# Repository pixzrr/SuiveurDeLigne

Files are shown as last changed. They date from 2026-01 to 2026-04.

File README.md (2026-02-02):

# SuiveurDeLigne

## Etape 1 : Créer le PCB
PCB : 100%


Carte imprimée

## Etape 2 : Soudure
Soudure : 100%

Tests : 8/9 validés (89%)

## Etape 3 : Programmation

Création des fonctions tests : terminé

Programmation en logique binaire (principe de sur-correction constante) : terminée

Programmation en logique analogique (s'adapter parfaitement à la courbe en fonction des nuances de gris) : en cours

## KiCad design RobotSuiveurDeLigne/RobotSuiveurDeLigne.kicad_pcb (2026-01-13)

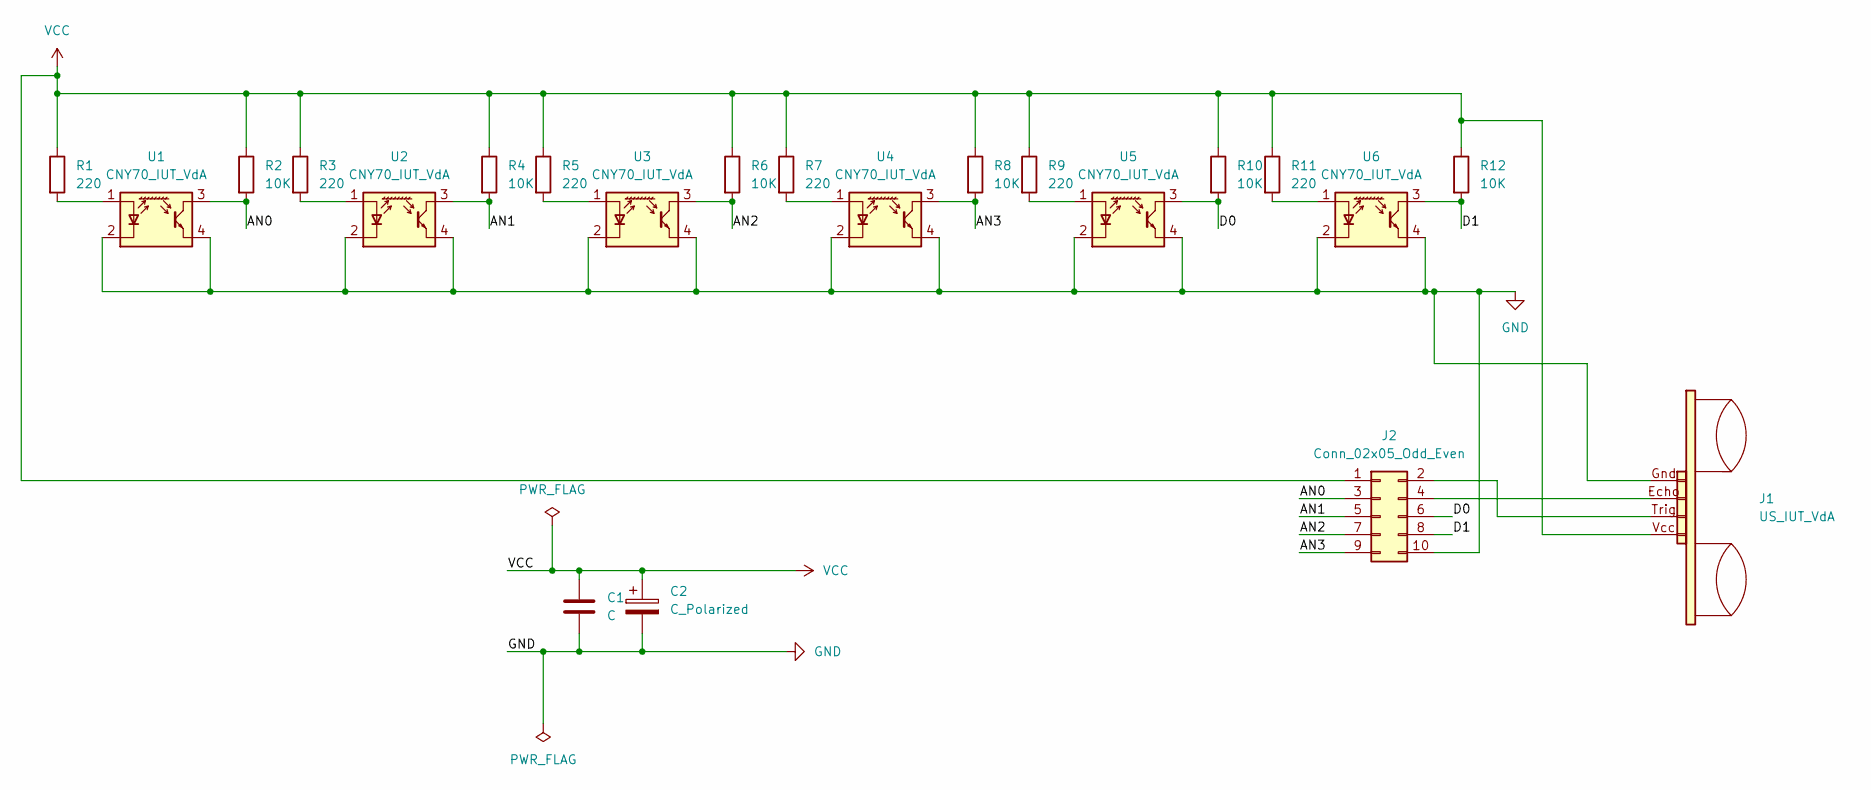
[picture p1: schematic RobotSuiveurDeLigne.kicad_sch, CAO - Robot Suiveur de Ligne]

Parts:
C1: C; C_Rect_L7.0mm_W6.5mm_P5.00mm
C2: C_Polarized; CP_Radial_D6.3mm_P2.50mm
J1: US_IUT_VdA; UltraSon_IUT_VdA
J2: Conn_02x05_Odd_Even; IDC-Header_2x05_P2.54mm_Horizontal
R1, R3, R5, R7, R9, R11: 220; R_Axial_DIN0207_L6.3mm_D2.5mm_P10.16mm_Horizontal
R2, R4, R6, R8, R10, R12: 10K; R_Axial_DIN0207_L6.3mm_D2.5mm_P10.16mm_Horizontal
U1, U2, U3, U4, U5, U6: CNY70_IUT_VdA; Vishay_CNY70

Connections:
/AN0: J2.3, R2.2, U1.3 (C)
/AN1: J2.5, R4.2, U2.3 (C)
/AN2: J2.7, R6.2, U3.3 (C)
/AN3: J2.9, R8.2, U4.3 (C)
/D0: J2.6, R10.2, U5.3 (C)
/D1: J2.8, R12.2, U6.3 (C)
GND: C1.2, C2.2, J1.Gnd, J2.10, U1.2 (K), U1.4 (E), U2.2 (K), U2.4 (E), U3.2 (K), U3.4 (E), U4.2 (K), U4.4 (E), U5.2 (K), U5.4 (E), U6.2 (K), U6.4 (E)
unnamed: J1.Trig, J2.2
unnamed: J1.Echo, J2.4
unnamed: R1.2, U1.1 (A)
unnamed: R3.2, U2.1 (A)
unnamed: R5.2, U3.1 (A)
unnamed: R7.2, U4.1 (A)
unnamed: R9.2, U5.1 (A)
unnamed: R11.2, U6.1 (A)
VCC: C1.1, C2.1, J1.Vcc, J2.1, R1.1, R2.1, R3.1, R4.1, R5.1, R6.1, R7.1, R8.1, R9.1, R10.1, R11.1, R12.1

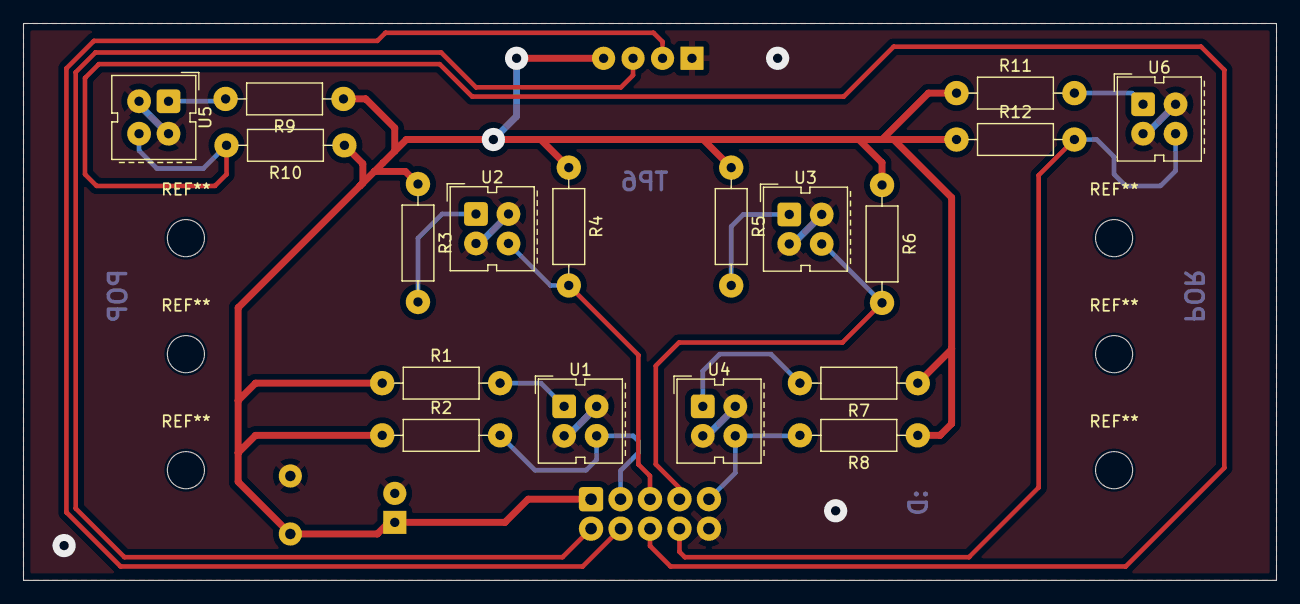
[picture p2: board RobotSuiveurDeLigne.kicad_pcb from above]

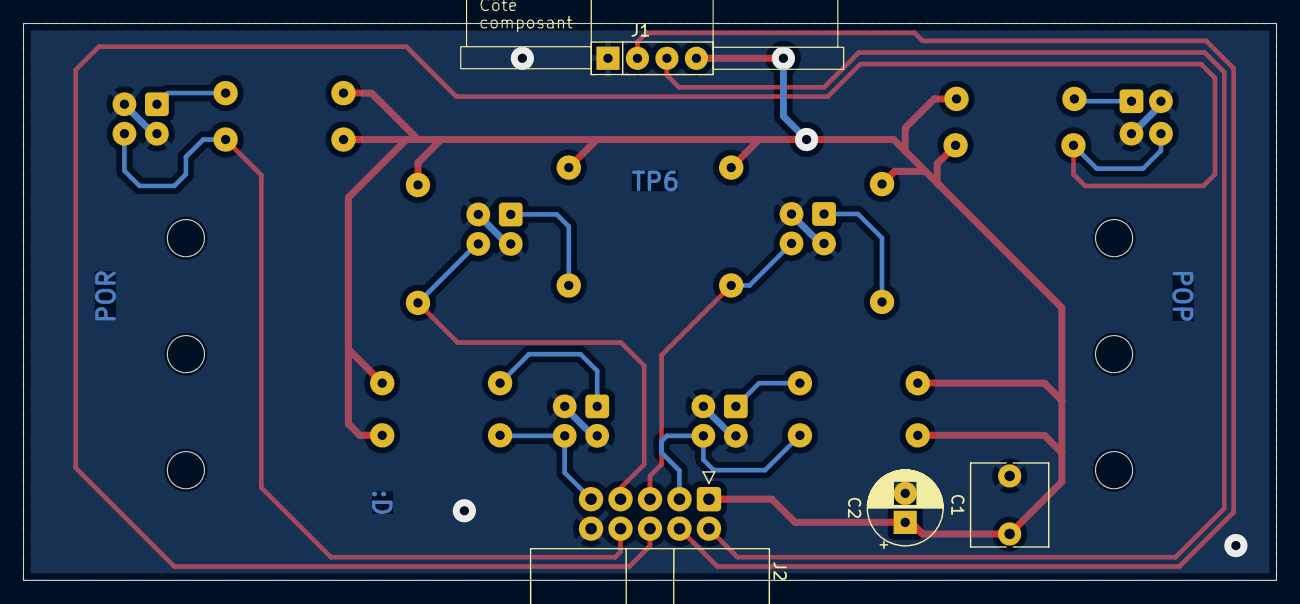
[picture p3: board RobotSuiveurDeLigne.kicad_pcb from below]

Board: 2 copper layers, 108.0 x 48.0 mm, 22 parts (4 on the bottom side), 16 nets.

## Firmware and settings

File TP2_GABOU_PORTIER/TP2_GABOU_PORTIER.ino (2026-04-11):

/*TP2
  PORTIER Gabriel
  GABOU Abel

  Projet Suiveur de Piste
  Robot TP2/1
  Date dernière modification : 09/04/2026 - Ajout de commentaires et structuration finale
*/

// ********************************************************************************************************************************************* //
// ********* Section 1 : Presets  ************************************************************************************************************** //
// ********************************************************************************************************************************************* //

// ──────────── Partie 1 : Inclusion des fichiers auxiliaires ──────────── //

#include "connexions_robot_arduino_uno.h"
#include "fonctions_test.h"
#include "actions_elementaires.h"
#include "actions_complexes.h"
#include "SonarVDA.h"

// ──────────── Partie 2 : Définition des constantes ───────────────── //

//Réglages selon l'exécution souhaitée
#define DEBEUG  0     // mettre 1 si le robot reste relié au PC (affichage CONSOLE)
                      // SINON 0
#define TEST    0     // mettre à 1 pour lancer un des tests
                      // SINON 0
  // Sélectionner un test :
  #define TEST_LED  0
  #define TEST_UART 0
  #define TEST_BATTERIE 0
  #define TEST_BP   0
  #define TEST_attendre_START 0
  #define TEST_attendre_START_en_boucle 0
  #define TEST_IR   0
  #define TEST_SONAR 1
  #define TEST_MOTEURS 0

//Paramètres de réglages
#define SEUIL_PRESENT 15  // distance en cm en dessous de laquelle un objet sera détecté
#define SEUIL_ABSENT  20  // distance en cm au dessus de laquelle un objet sera plus détecté


// ──────────── Partie 3 : Paramétrage des variables globales──────────── //

int mode = MODE_NORMAL; // variable définie dans actions_complexes.h

SonarVDA sonar; //Céation d'un objet "sonar" de classe "SonarVDA"
volatile bool obstacle_proche = false; //variable faisant le lien avec les fonction d'interruption

//Prototypes :
void test(void);
void obstacle_present(void);//Programme de gestion d'un obstacle
void obstacle_absent(void);//Programme de gestion de la disparition de l'obstacle

// ********************************************************************************************************************************************* //







// ********************************************************************************************************************************************* //
// ********* Section 2 : APPLICATIONS : setup() et loop()  ************************************************************************************* //
// ********************************************************************************************************************************************* //

// ──────────── Partie 1 : Setup ───────────────────────────── //

// the setup routine runs once when you press reset:
void setup() {  
  if(DEBEUG){Serial.begin(9600);}// initialize serial communication at 9600 bits per second:
  init_pin();
  
  if(TEST){test();}

  // Setup sonar
  sonar.set_trigger(SEUIL_PRESENT, SEUIL_ABSENT, obstacle_present, obstacle_absent); 
  sonar.start();
}

// ──────────── Partie 2 : Loop ───────────────────────────── //

void loop() {  

  // ----------- Vérifier boutton start ----------- //

  // Setup boutton start
  static bool verif_boutton_start = 0;
  
  if (verif_boutton_start == 0) {
    attendre_START();
    while (digitalRead(PIN_BP) == 1) {} // attendre que le bouton soit relaché pour éviter de gacher la fonction d'arret
    verif_boutton_start = 1;
  }
  

  // ---------------- Gestion Sonar ----------------- //

  if (obstacle_proche == true) {
    analogWrite(PIN_M_GAUCHE_A, 0);
    analogWrite(PIN_M_GAUCHE_R, 0);
    analogWrite(PIN_M_DROIT_A, 0);
    analogWrite(PIN_M_DROIT_R, 0);
    while (obstacle_proche == true) {}
  }
  

// ------------------ On met des conditions avec mode pour éviter que le robot fasse un 360 ou suive la courbe pendant un raccourci par exemple ------------------- //

  if (mode ==  MODE_NORMAL) suivre_courbure();

  raccourci();
  
  if (mode != MODE_RACCOURCI) stop_360();


  //  ----------- Si tout est blanc, on s'arrête par précaution  ou  Si l'utilisateur appuie sur le boutton encore une fois, le robot s'arrête ----------- //
    
    if ((digitalRead(PIN_IR2) == 1 && digitalRead(PIN_IR3) == 1 && digitalRead(PIN_IR4) == 1 && digitalRead(PIN_IR5) == 1) || digitalRead(PIN_BP) == 1 && verif_boutton_start == 1) {
      analogWrite(PIN_M_GAUCHE_A, 0);
      analogWrite(PIN_M_GAUCHE_R, 0);
      analogWrite(PIN_M_DROIT_A, 0);
      analogWrite(PIN_M_DROIT_R, 0);
      verif_boutton_start = 0;
    }
}

// ********************************************************************************************************************************************* //






// ********************************************************************************************************************************************* //
// ********* Section 3 : APPLICATIONS : test() et instructions liées aux interruptions  ******************************************************** //
// ********************************************************************************************************************************************* //

// ──────────── Partie 1 : Fonction test ──────────────────────── //

// Lancement de fonctions de tests 
//NB : constantes à régler en début de code selon tests désirées
void test(void){
  if(TEST_LED){test_led_en_boucle();}
  if(TEST_UART && DEBEUG){test_uart_en_boucle();}
  if(TEST_BATTERIE && DEBEUG){affiche_tention_batterie();}
  if(TEST_BP && DEBEUG){test_bouton_poussoir_en_boucle();}
  if(TEST_attendre_START && DEBEUG){ attendre_START();}
  if(TEST_attendre_START_en_boucle && DEBEUG){ test_attendre_START_en_boucle();}
  if(TEST_IR && DEBEUG){ test_capteurs_IR();}
  if(TEST_SONAR && DEBEUG){test_sonar_en_boucle(sonar, SEUIL_PRESENT, SEUIL_ABSENT, obstacle_present, obstacle_absent);}
  if(TEST_MOTEURS && DEBEUG){test_moteurs();}
}

// ──────────── Partie 2 : Instructions d'interruption ──────────────── //

//Fonction exécutée à l'apparition d'un obstacle
void obstacle_present(void){
   obstacle_proche = true;
   Serial.println(" Objet present");   
}

//Fonction exécutée à la disparition d'un obstacle
void obstacle_absent(void){
   obstacle_proche = false;
   Serial.println(" Objet absent");
}

// ********************************************************************************************************************************************* //

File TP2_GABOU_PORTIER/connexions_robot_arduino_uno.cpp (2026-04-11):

#include "connexions_robot_arduino_uno.h"

void init_pin(void){    

// ──────────── Partie 1 : LED, BP, Batterie ───────────────────── //

  pinMode(PIN_LED, OUTPUT); // initialize digital pin LED_BUILTIN as an output.  
  pinMode(PIN_BP, INPUT); // make the pushbutton's pin an input.

  pinMode(PIN_TENSION_REDUITE_BATTERIE, INPUT); // Met le pin de tension reduite de la batterie en entrée

// ──────────── Partie 2 : Capteurs IR ──────────────────────── //

  pinMode(PIN_IR1, INPUT);
  pinMode(PIN_IR2, INPUT);
  pinMode(PIN_IR3, INPUT);
  pinMode(PIN_IR4, INPUT);
  pinMode(PIN_IR5, INPUT);
  pinMode(PIN_IR6, INPUT);

// ──────────── Partie 3 : Moteurs ────────────────────────── //

    // Moteur droit
  pinMode(PIN_M_DROIT_A, OUTPUT);
  pinMode(PIN_M_DROIT_R, OUTPUT);
  
    // Moteur gauche
  pinMode(PIN_M_GAUCHE_A, OUTPUT);
  pinMode(PIN_M_GAUCHE_R, OUTPUT);
}

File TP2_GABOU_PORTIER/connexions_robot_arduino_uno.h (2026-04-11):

/* Ressources utilisées :
  Timers 0 8bits :        > Moteur 1 :
    OC0A = PD6 =  D6  IO6   > Cmd_1A
    OC0B = PD5 =  D5  IO5   > Cmd_1B
  Timers 1 16bits:        > Sonar :
    ICP1 = PB0 =  D8  IO8   > US_echo
    OC1A = PB1 =  D9  IO9
    OC1B = PB2 =  D10 SS    > US_trig
  Timers 2 8bits:         > Moteur 2 :
    OC2A = PB3 =  D11 MOSI  > Cmd_2A
    OC2B = PD3 =  D3  IO3   > Cmd_2B
*/

#ifndef connexions_robot_arduino_uno_h
  #define connexions_robot_arduino_uno_h

  #include <Arduino.h>

// ──────────── Partie 1 : LED, BP, Batterie ───────────────────── //

  #define PIN_LED 13 // LED
  #define PIN_BP 12 //Bouton poussoir
  #define PIN_TENSION_REDUITE_BATTERIE A4 // Tension réduite batterie

  #define PIN_BATT A123456 //Image de la tension de la Batterie

// ──────────── Partie 2 : Capteurs IR ──────────────────────── //

  // Capteurs IR de gauche à droite, vue derrière le robot
  #define PIN_IR1 4
  #define PIN_IR2 A3
  #define PIN_IR3 A2
  #define PIN_IR4 A1
  #define PIN_IR5 A0
  #define PIN_IR6 7

// ──────────── Partie 3 : Moteurs ────────────────────────── //

    // Moteur droit
  #define PIN_M_DROIT_A 5
  #define PIN_M_DROIT_R 6
  
    //Moteur gauche
  #define PIN_M_GAUCHE_A 3
  #define PIN_M_GAUCHE_R 11

  // Puissances moteurs
    // Lent
  #define RAPIDE 255
    // Rapide
    #define LENT 180




  void init_pin(void);

#endif

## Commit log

2025-09-15 premier commit
    [RobotSuiveurDeLigne.kicad_pcb, RobotSuiveurDeLigne.kicad_sch]
2025-09-15 modifs shéma
    [RobotSuiveurDeLigne.kicad_sch]
2025-09-22 ajout empreintes pour routage
    [RobotSuiveurDeLigne.kicad_sch]
2026-01-13 PCB final
    envoyé pour impression
    [Fiche2_CAO_A_valider_avant_Gravure.ods, RobotSuiveurDeLigne.kicad_pcb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]
2026-01-30 Version binaire
    Programme fonctionnel sur une des deux cartes
2026-01-30 Ajout fonction rapport vitesse
    Pour tourner en fonction de l'angle de courbure
2026-02-01 Affinage fonction suivre_courbure
    - nouvelle methode : fonction affine
    - déplacement de la fonction vers actions_complexes.cpp +.h
2026-02-02 Version analogique
    tourne bien mais suit pas la ligne
2026-02-02 Correction de l'autonomie des moteurs
    Les moteurs fonctionnaient individuellement, et ne prenaient pas en compte la correction de l'autre moteur, donc j'ai fait une différence pour calculer l'erreur entre les deux mesures. Si = 0, on peut aller tout droit (d'où le 255- 0,5*vitesseIR)
    [TP2_GABOU_PORTIER.ino, actions_complexes.cpp]
2026-02-02 Optimisations
    if (erreur == 0) enlevé, cette condition est inutile, surtout qu'elle ne sera jamais vérifiée (sauf par concours de circonstances)
    [actions_complexes.cpp]
2026-02-03 corrections
    correction suivi de courbures
    correction marche / arrêt
    [TP2_GABOU_PORTIER.ino, actions_complexes.cpp, actions_elementaires.cpp]
2026-03-13 ajout 360 v2 + millis
2026-03-29 rework raccourci + ajout version m.etats
    [TP2_GABOU_PORTIER.ino, actions_complexes.cpp]
2026-04-11 Restructuration finale
    - ajout de commentaires
    - structuration par parties
    - corrections mineures
    [TP2_GABOU_PORTIER.ino, actions_complexes.cpp, actions_elementaires.cpp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]
